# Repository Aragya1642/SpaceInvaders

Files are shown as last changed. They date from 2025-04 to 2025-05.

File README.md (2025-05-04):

# Space Invaders Bop-It

The Space Invaders Bop-It is an embedded interactive game that combines the reflex-based mechanics of Bop-It with the space-themed gameplay of Space Invaders. Built around the ATMega328P microcontroller, this project incorporates physical controls, audio/visual feedback, and a custom PCB to deliver an engaging and fast-paced user experience.

## Overview

Players are prompted with random commands such as:

- Turn Left
- Turn Right
- Throttle Up
- Shoot

Each command corresponds to one of the three physical inputs:
- Steering Wheel
- Throttle Lever
- Push Button

Correct responses increase the player’s score, flash a green LED, and play a "ding" sound. Incorrect or delayed responses trigger a red LED, a crash sound, and reset the game. The objective is to reach a score of 99 without failure.

## Features

- Three unique analog/digital inputs: steering, throttle, fire
- LCD screen to display real-time score
- DFPlayer Mini for audio feedback via speakers
- LED indicators for success and failure
- Finite State Machine logic with decreasing response time per successful input
- Enclosure design using Onshape CAD and laser-cut acrylic
- Custom PCB built in KiCad with support for power regulation, audio, and I/O

## Repository Structure

├── src/ # Arduino software

├── pcb/ # KiCad PCB design files

├── cad/ # CAD screenshots and Onshape link

├── docs/ # Final report and additional documentation

├── media/ # Photos and video demonstration

├── LICENSE

└── README.md

## How to Build

1. Clone this repository:
https://github.com/iamratedpg13/SpaceInvaders.git

2. Upload `src/main.ino` to an ATMega328P or Arduino Uno-compatible board.

3. Assemble the PCB using the files in the `pcb/` directory.

4. 3D print or laser cut enclosure parts using the files or images in `cad/`.

5. Copy required `.mp3` sound files to a FAT32-formatted microSD card and insert it into the DFPlayer Mini module.

6. Power the system using a regulated 5V supply (e.g., 9V battery with onboard regulator).

## Video Demo

Watch the game in action:  
https://www.youtube.com/watch?v=FF51uR-_Np4

## Key Implementation Notes

- The throttle and wheel are analog inputs (potentiometers); the button is digital.
- AVCC on the ATMega must be tied to 5V for proper ADC operation.
- Sound and display use UART and I2C, respectively; serial conflicts were resolved manually.
- Input drift was corrected in software by sampling baseline values at startup.

## Team Members

- PJ Granieri – Hardware and PCB Design
- Joshua Krymgold – Software Development
- Aragya Goyal – Enclosure Design and CAD

## License

This project is licensed under the MIT License. See the LICENSE file for details.

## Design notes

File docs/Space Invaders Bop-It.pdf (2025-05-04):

# Space Invaders Bop-It

## ECE 1895 - Aragya Goyal, Joshua Krymgold, PJ Granieri

The Main Idea

Our Bop-It project is inspired from a familiar game, known as Space Invaders. However, it differs greatly from the original game, as instead of only shooting down invaders, the player is also responsible for maneuvering the space shuttle as well as applying the throttle to accelerate out of troublesome situations.

## Three Main Goals

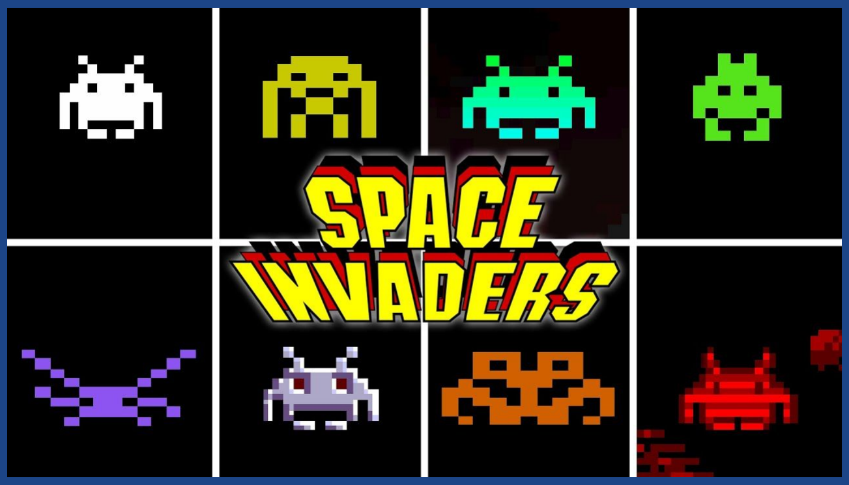
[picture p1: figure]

## 1. Shoot down the Invaders 2. Navigate through the domain of space 3. Accelerate out of any trouble that arises

01

## Enclosure

Designing the housing

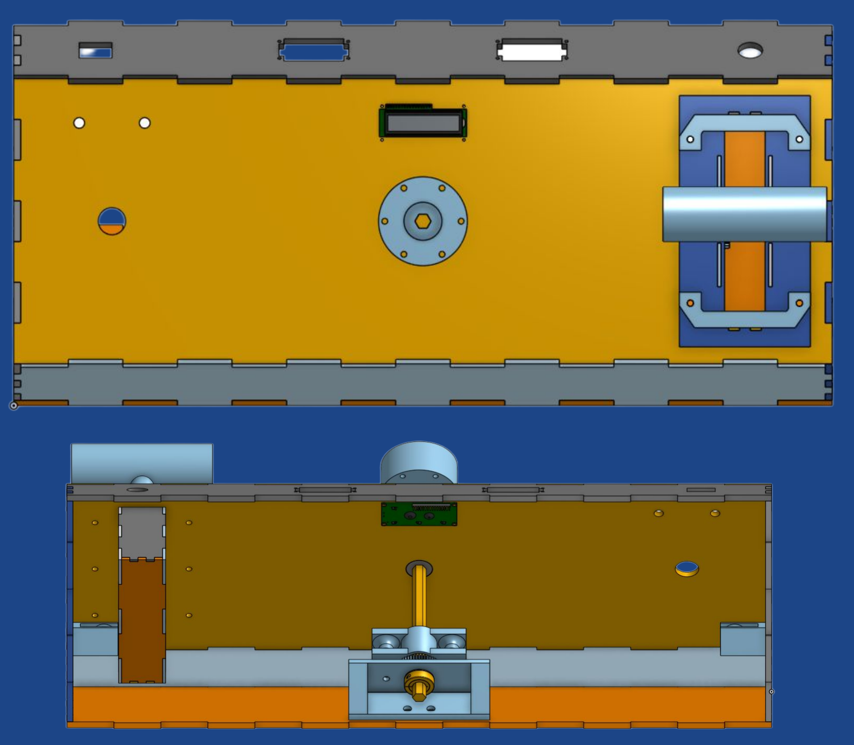
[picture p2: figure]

## CAD Design (Onshape)

- Laser Cut Acrylic
- Main Body
- Throttle Holder
- 3D Printed Parts
- Steering Column
- Throttle Handle
- COTS Parts
- Steering Wheel
- Bungee Cords

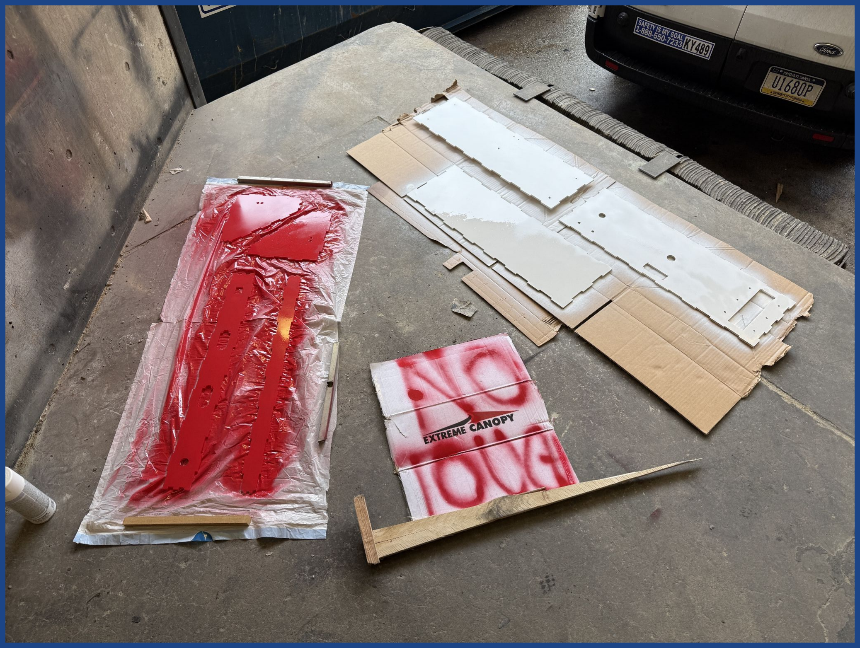
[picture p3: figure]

## Aesthetics

## - Spray painted for aesthetic - Removable Steering Wheel

02

## Electronics/Software

Building the brains

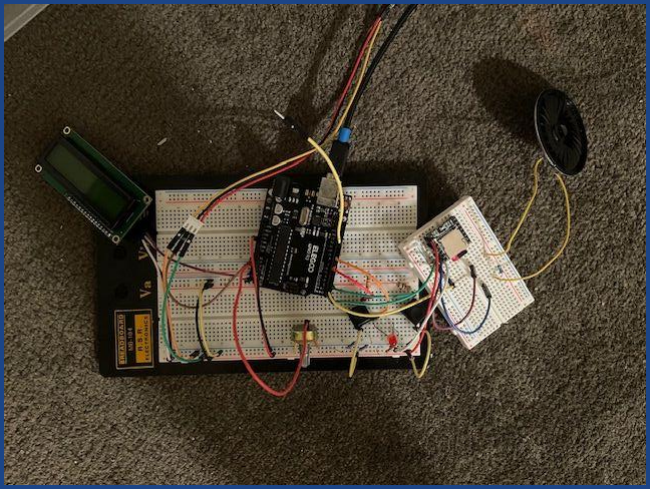
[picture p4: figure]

# Breadboar

d

### - Designed in components - Slowly assembled after testing each individual component - Only major issue was Software Serial

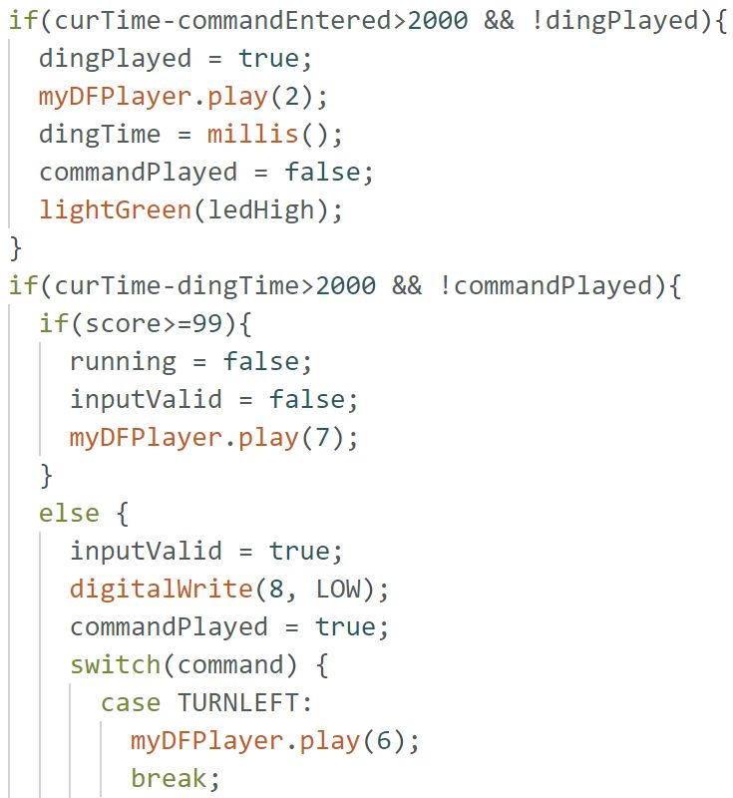
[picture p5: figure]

## Software

### - Timing was a common problem - Best solution was FSM - Ended up making sudo FSM using booleans

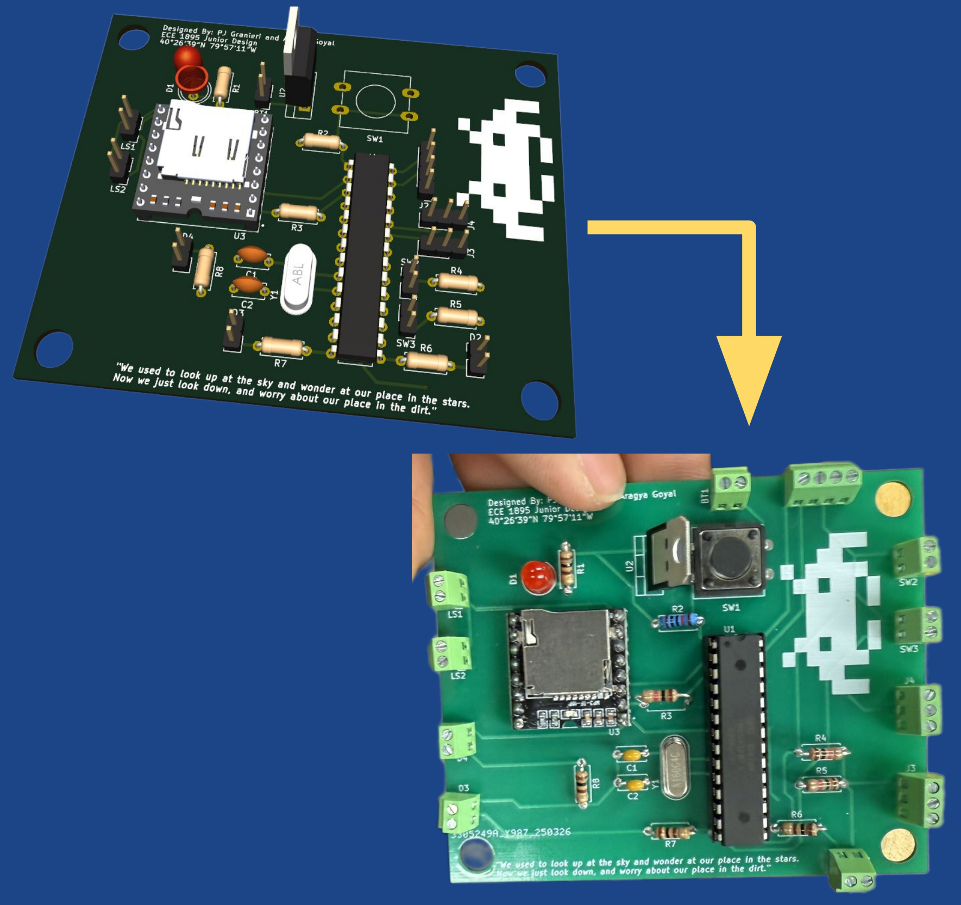
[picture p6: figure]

## PCB Design (KiCAD)

- DF Player w/ SD Card
- Two Speakers
- LCD Display
- Voltage Regulator
- Two Encoders
- Two Press Buttons
- Crystal Oscillator
- Green LED
- Red LED

03

## Assembly/Integration

Putting it all together

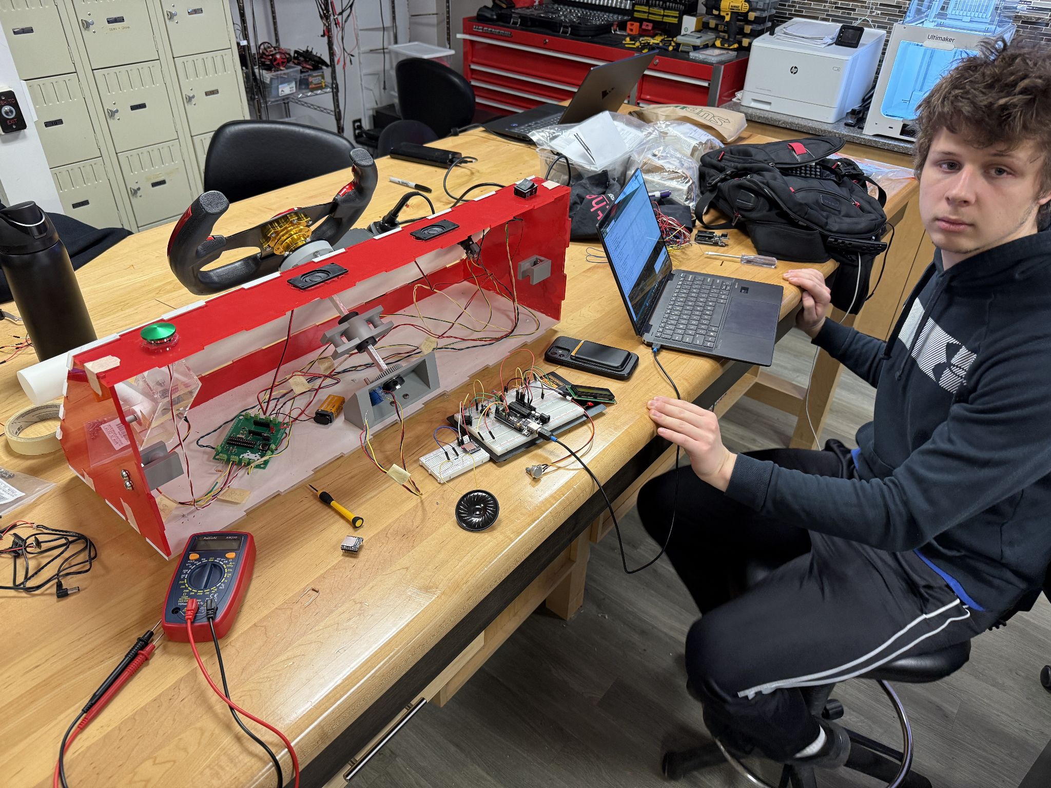
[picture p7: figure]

## The AVCC Problem

Problem:
- Potentiometers were
giving random inputs
- Worked Correctly at 5V
and 0V
Solution:
- AVCC must also be tied to high in order for ADC to
have a reference voltage

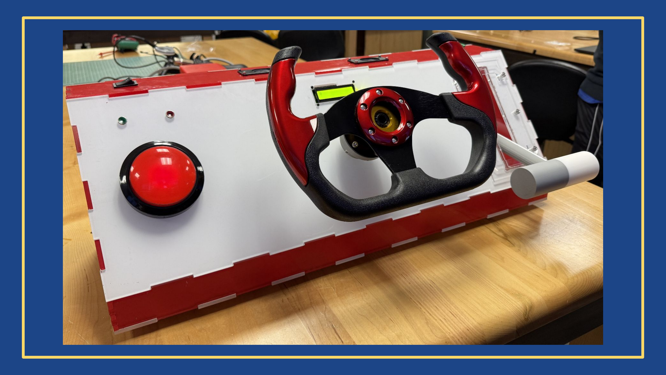
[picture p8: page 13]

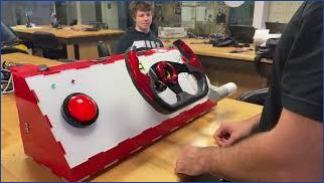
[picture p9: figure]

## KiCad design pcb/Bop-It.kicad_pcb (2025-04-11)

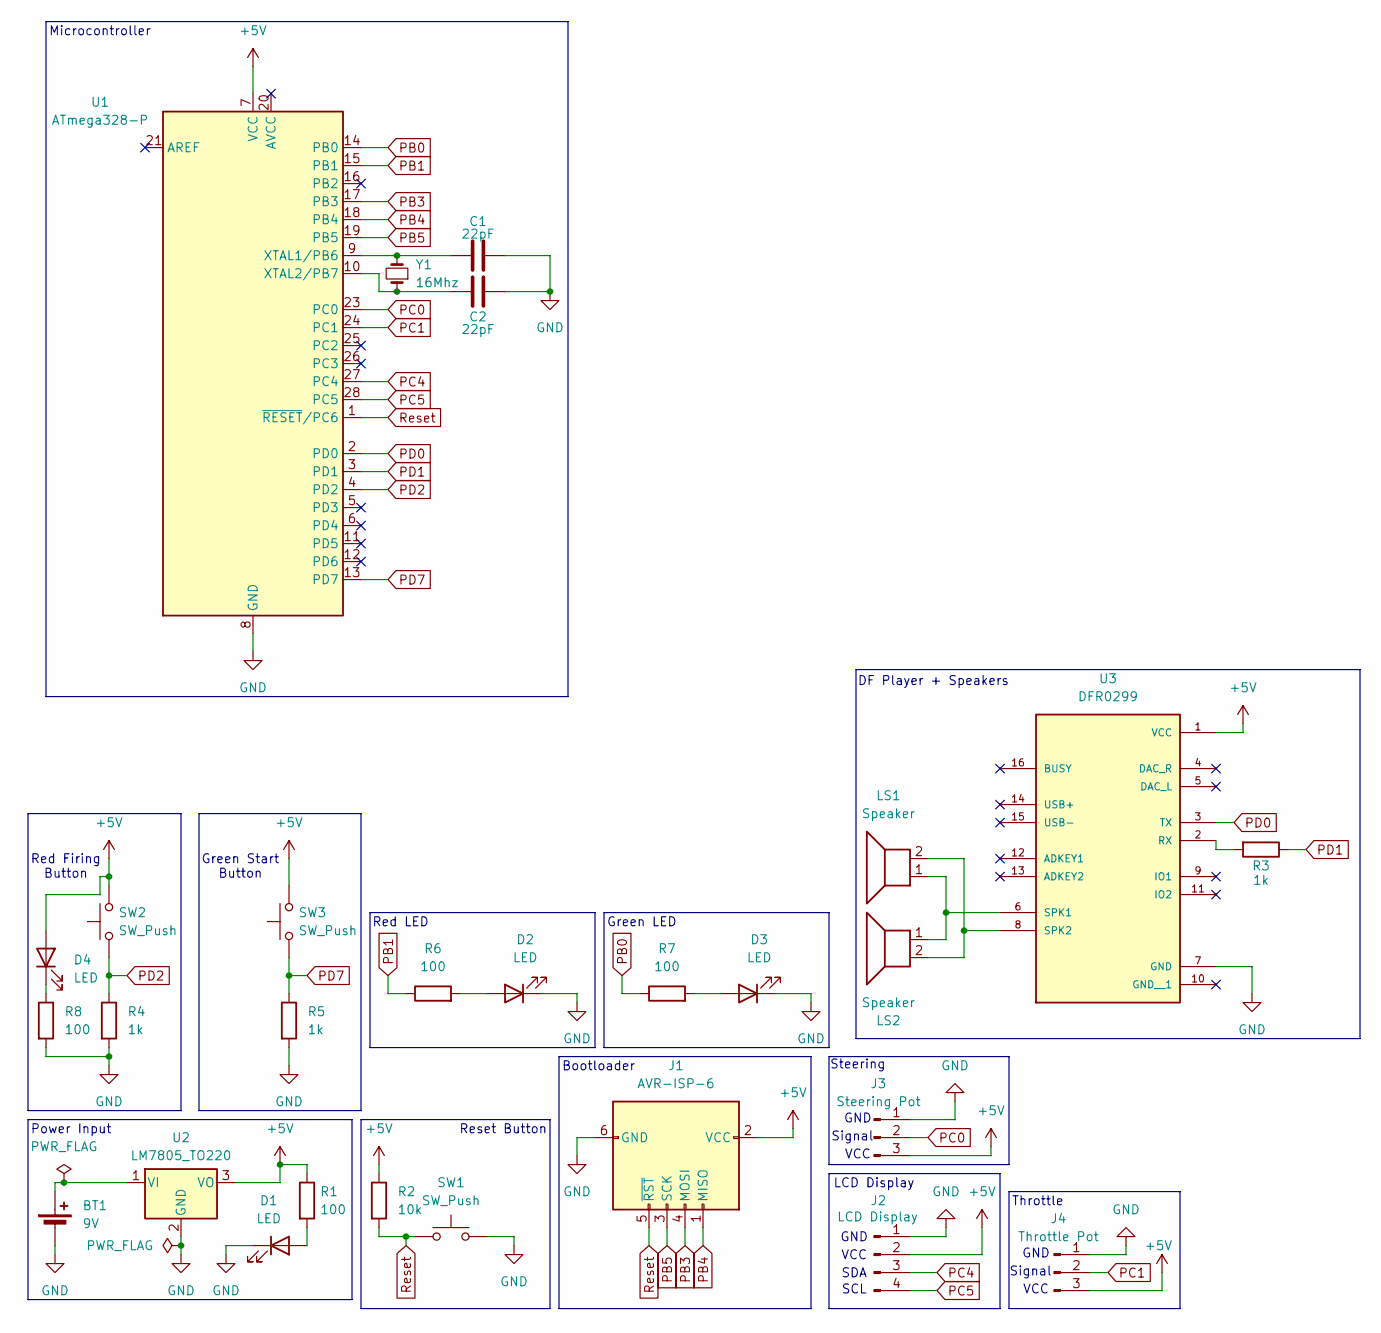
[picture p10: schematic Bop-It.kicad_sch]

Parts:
BT1: 9V; PinHeader_1x02_P2.54mm_Vertical
C1, C2: 22pF; C_Disc_D5.0mm_W2.5mm_P5.00mm
D1: LED; LED_D5.0mm
D2, D3, D4: LED; PinHeader_1x02_P2.54mm_Vertical
J1: AVR-ISP-6; PinHeader_2x03_P2.54mm_Vertical
J2: LCD Display; PinHeader_1x04_P2.54mm_Vertical
J3: Steering Pot; PinHeader_1x03_P2.54mm_Vertical
J4: Throttle Pot; PinHeader_1x03_P2.54mm_Vertical
LS1, LS2: Speaker; PinHeader_1x02_P2.54mm_Vertical
R1, R6, R7, R8: 100; R_Axial_DIN0207_L6.3mm_D2.5mm_P7.62mm_Horizontal
R2: 10k; R_Axial_DIN0207_L6.3mm_D2.5mm_P7.62mm_Horizontal
R3, R4, R5: 1k; R_Axial_DIN0207_L6.3mm_D2.5mm_P7.62mm_Horizontal
SW1: SW_Push; SW_PUSH-12mm
SW2, SW3: SW_Push; PinHeader_1x02_P2.54mm_Vertical
U1: ATmega328-P; DIP-28_W7.62mm
U2: LM7805_TO220; TO-220-3_Vertical
U3: DFR0299; MODULE_DFR0299
Y1: 16Mhz; XTAL_HC49P488W46L1150T500H350

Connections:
+5V: D4.2 (A), J1.2 (VCC), J2.2, J3.3, J4.3, R1.1, R2.1, SW2.2, SW3.2, U1.7 (VCC), U2.3 (VO), U3.1 (VCC)
GND: BT1.2 (-), C1.2, C2.2, D1.1 (K), D2.1 (K), D3.1 (K), J1.6 (GND), J2.1, J3.1, J4.1, R4.2, R5.2, R8.2, SW1.2, U1.8 (GND), U1.22 (GND), U2.2 (GND), U3.7 (GND)
unnamed: BT1.1 (+), U2.1 (VI)
unnamed: D1.2 (A), R1.2
unnamed: D2.2 (A), R6.2
unnamed: D3.2 (A), R7.2
unnamed: D4.1 (K), R8.1
unnamed: C1.1, U1.9 (XTAL1/PB6), Y1.2
unnamed: C2.1, U1.10 (XTAL2/PB7), Y1.1
unnamed: R3.2, U3.2 (RX)
unnamed: LS1.1, LS2.1, U3.6 (SPK1)
unnamed: LS1.2, LS2.2, U3.8 (SPK2)
PB0: R7.1, U1.14 (PB0)
PB1: R6.1, U1.15 (PB1)
PB3: J1.4 (MOSI), U1.17 (PB3)
PB4: J1.1 (MISO), U1.18 (PB4)
PB5: J1.3 (SCK), U1.19 (PB5)
PC0: J3.2, U1.23 (PC0)
PC1: J4.2, U1.24 (PC1)
PC4: J2.3, U1.27 (PC4)
PC5: J2.4, U1.28 (PC5)
PD0: U1.2 (PD0), U3.3 (TX)
PD1: R3.1, U1.3 (PD1)
PD2: R4.1, SW2.1, U1.4 (PD2)
PD7: R5.1, SW3.1, U1.13 (PD7)
Reset: J1.5 (~RST), R2.2, SW1.1, U1.1 (~RESET/PC6)

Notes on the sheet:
Steering
VCC
DF Player + Speakers
GND
SDA
Throttle
Signal
Red LED
Reset Button
Bootloader
Power Input
LCD Display
Green LED
SCL
Red Firing Button
Green Start Button
Microcontroller

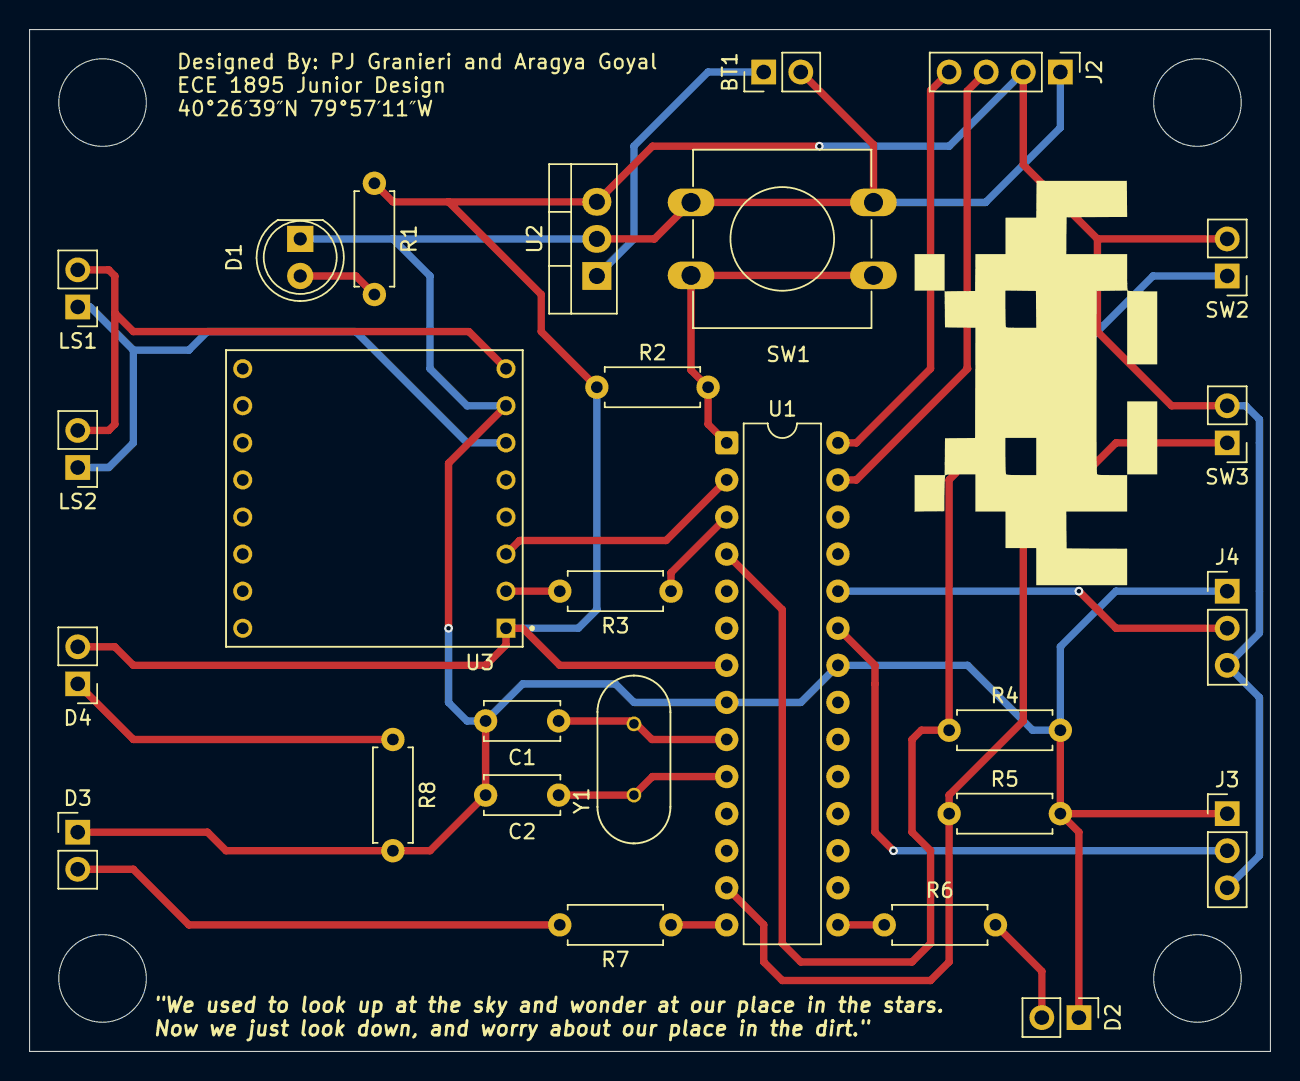
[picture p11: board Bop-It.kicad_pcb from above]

Board: 2 copper layers, 85.0 x 70.0 mm, 27 parts (0 on the bottom side), 23 nets.

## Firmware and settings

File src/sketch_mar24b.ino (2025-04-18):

#include <DFRobotDFPlayerMini.h>
#include <LiquidCrystal_I2C.h>


#define NUMCOMMANDS 4
//#define giveRandomCommand() rand()%4
#define THROTTLEUP 3
#define PRESSBUTTON 2
#define TURNRIGHT 1
#define TURNLEFT 0

#define getThrottleAngle() analogRead(A1)
#define getSteeringAngle() analogRead(A0)
#define lightGreen(ledHigh) digitalWrite(8, HIGH); ledHigh = true
#define getRedButtonPressed() digitalRead(2)

int val = 0;
int start;
int command;
bool running = false;
int score = 0;
bool ledHigh = false;
int commandEntered = 10000;
int dingTime = 10000;
bool commandPlayed = true;
bool dingPlayed = true;
int timeLeft = 20000;
double thisTime = 1;
int steeringMiddle;
LiquidCrystal_I2C lcd(0x27,  20, 2);
bool inputValid = false;
//#if (defined(ARDUINO_AVR_UNO) || defined(ESP8266))   // Using a soft serial port
//#include <SoftwareSerial.h>
//SoftwareSerial softSerial(/*rx =*/10, /*tx =*/11);
//#define FPSerial softSerial
//#else
#define FPSerial Serial
//#endif

DFRobotDFPlayerMini myDFPlayer;

void failure(){
  running = false;
  inputValid = false;
  digitalWrite(8, LOW);
  digitalWrite(9, HIGH);
  myDFPlayer.play(3);
}

int giveRandomCommand(){
      command = rand()%4;
      /*switch(command) {
        case TURNLEFT:
          myDFPlayer.play(6);
          break;
        case TURNRIGHT:
          myDFPlayer.play(5);
          break;
        case PRESSBUTTON:
          myDFPlayer.play(4);
          break;
        case THROTTLEUP:
          myDFPlayer.play(9);
          break;
      }*/
      return command;
}

void setup() {
  // put your setup code here, to run once:
  FPSerial.begin(9600);
  //Serial.begin(115200);
  pinMode(9, OUTPUT);
  pinMode(2, INPUT);
  pinMode(7, INPUT);
  lcd.init();
  lcd.backlight();
  lcd.setCursor(0,0);
  lcd.print(score);
  digitalWrite(9, LOW);
  steeringMiddle = analogRead(A0);
  //Serial.println("here");
  if (!myDFPlayer.begin(FPSerial, /*isACK = */true, /*doReset = */true)) {  //Use serial to communicate with mp3.
    //Serial.println(F("Unable to begin:"));
    //Serial.println(F("1.Please recheck the connection!"));
    //Serial.println(F("2.Please insert the SD card!"));
    while(true){
      delay(0); // Code to compatible with ESP8266 watch dog.
    }
  }
  //Serial.println(F("DFPlayer Mini online."));
  myDFPlayer.volume(30);
  //myDFPlayer.play(1);
}

void loop() {
  //Serial.println(digitalRead(7));
  if(running){
  //Serial.println("here");
  // put your main code here, to run repeatedly:
  int curTime = millis();
  int throttleAngle = getThrottleAngle();
  int steeringAngle = getSteeringAngle();
  bool buttonPressed = getRedButtonPressed();
  int lightStart = 1000;
  //val = analogRead(A1);
  int input = -1;
  int timePassed = curTime-start;
  int soundToPlay = -1;
  ///dingTime = 1000000;
  //commandEntered=curTime;
  //dingTime=curTime;
  if(curTime-commandEntered>2000 && !dingPlayed){
    dingPlayed = true;
    myDFPlayer.play(2);
    dingTime = millis();
    commandPlayed = false;
    lightGreen(ledHigh);
  }
  if(curTime-dingTime>2000 && !commandPlayed){
    if(score>=99){
      running = false;
      inputValid = false;
      myDFPlayer.play(7);
    }
    else {
      inputValid = true;
      digitalWrite(8, LOW);
      commandPlayed = true;
      switch(command) {
        case TURNLEFT:
          myDFPlayer.play(6);
          break;
        case TURNRIGHT:
          myDFPlayer.play(5);
          break;
        case PRESSBUTTON:
          myDFPlayer.play(4);
          break;
        case THROTTLEUP:
          myDFPlayer.play(9);
          break;
        }
      start = millis();
    }
  }
  /*if(timePassed>1000){
    start = millis();
    command = giveRandomCommand();
  }*/
  //end the blink of the led
  /*if(ledHigh && timePassed>250){
    ledHigh = false;
  }*/
  //assign the correct inputs
  if(timePassed>2000){
    if(steeringAngle > steeringMiddle+25)//537)//512
      input = TURNRIGHT;
    if(steeringAngle < steeringMiddle-25)//487)
      input = TURNLEFT;
  }
  if(throttleAngle > 800 && timePassed>2000 ){
    input = THROTTLEUP;
    //myDFPlayer.play(8);
    soundToPlay = 8;
  }
  if(buttonPressed && timePassed>500){
    input = PRESSBUTTON;
    //myDFPlayer.play(1);
    soundToPlay = 1;
  }
  //end assign the correct inputs
  //if the input is correct, light up the led, restart the countdown, give a new command, and increment the score
  if(command==input && inputValid){
    //Serial.println("good job");
    //myDFPlayer.play(2);
    //start = millis();
    inputValid = false;
    dingPlayed = false;
    command = giveRandomCommand();
    //Serial.println(command);
    score++;
    lcd.clear();
    lcd.setCursor(0,0);
    lcd.print(score);
    //delay(1000);
    if(soundToPlay>-1){
      myDFPlayer.play(soundToPlay);
    }
    thisTime/=1.0392;
    timeLeft=10000*thisTime+10000;
    commandEntered = millis();
  }
  else if(command!=input && input!=-1 && dingPlayed && commandPlayed){
    failure();
  }
  if(digitalRead(7)){
    running = false;
  }
  if(timePassed>timeLeft){
    failure();
  }
  }
  else
    if(!running){
      running = digitalRead(7);
      //Serial.println("this");
      //Serial.println(running);
      if(running){
        start = millis();
        score = 0;
        command = giveRandomCommand();
        inputValid = true;
        timeLeft = 20000;
        thisTime = 1;
        lcd.clear();
        lcd.setCursor(0,0);
        lcd.print(score);
        digitalWrite(9, LOW);
        switch(command) {
          case TURNLEFT:
            myDFPlayer.play(6);
            break;
          case TURNRIGHT:
            myDFPlayer.play(5);
            break;
          case PRESSBUTTON:
            myDFPlayer.play(4);
            break;
          case THROTTLEUP:
            myDFPlayer.play(9);
            break;
        }
      }
      dingPlayed = true;
      commandPlayed = true;
      //lcd.setCursor(0,0);
      //lcd.print(score);
      //Serial.println(command);
    }
  //Serial.println(val);
}

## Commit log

2025-03-21 Spaceinvaders PCB design schematic
    [SpaceInvaders.kicad_pcb, SpaceInvaders.kicad_sch]
2025-04-11 Updated PCB Files
    [Bop-It.kicad_pcb, Bop-It.kicad_sch]
2025-05-04 Delete SpaceInvaders.kicad_sch
    Outdated file cleanup
    [SpaceInvaders.kicad_sch]
2025-05-04 Delete ~SpaceInvaders.kicad_sch.lck
    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
2025-05-04 Delete SpaceInvaders.kicad_pro
    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
2025-05-04 Delete SpaceInvaders.kicad_prl
    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
2025-05-04 Delete SpaceInvaders.kicad_pcb
    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
    [SpaceInvaders.kicad_pcb]
2025-05-04 Repo cleanup
    [Bop-It.kicad_pcb]
2025-05-04 Update and rename Bop-It.kicad_sch to pcb/Bop-It.kicad_sch
    [Bop-It.kicad_sch]
2025-05-04 PCB Photo
